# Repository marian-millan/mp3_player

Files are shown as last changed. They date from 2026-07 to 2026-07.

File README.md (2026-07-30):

<div align="center">

# Portable MP3 Player

### A custom, distraction-free music player inspired by retro physical media

**KiCad 9 · Arduino · DFPlayer Mini · SSD1306 OLED**

</div>

## Overview

We love music, but wanted a way to listen without constantly reaching for a
phone and getting distracted. Inspired by the tactile feel of retro physical
media, we set out to build a dedicated hardware MP3 player.

This repository contains versioned hardware designs, assembled-board models,
and Arduino firmware. The player combines physical transport controls and a
rotary volume encoder with a compact OLED interface.

## Features

- Standalone MP3 playback through a DFRobot DFPlayer Mini
- 128 × 64 SSD1306 OLED interface
- Previous, play/pause, and next track buttons
- Rotary encoder volume control
- Custom KiCad schematic and two-layer PCB layout
- STEP model of the assembled board

## Repository Layout

| Path | Contents |
| --- | --- |
| [`versions/v1/firmware`](versions/v1/firmware) | Version 1 Arduino firmware |
| [`versions/v1/hardware/mp3_player_schematic_v1.kicad_sch`](versions/v1/hardware/mp3_player_schematic_v1.kicad_sch) | Version 1 KiCad schematic |
| [`versions/v1/hardware/mp3_player_pcb_v1.kicad_pcb`](versions/v1/hardware/mp3_player_pcb_v1.kicad_pcb) | Version 1 KiCad PCB layout |
| [`versions/v1/hardware/mp3_player_assembly_v1.step`](versions/v1/hardware/mp3_player_assembly_v1.step) | Version 1 assembled-board model |
| [`versions/v2`](versions/v2) | Version 2 placeholder—in development |

```text
versions/
├── v1/
│   ├── firmware/
│   │   └── mp3_player_v1/
│   │       └── mp3_player_v1.ino
│   └── hardware/
│       ├── mp3_player_assembly_v1.step
│       ├── mp3_player_pcb_v1.kicad_pcb
│       └── mp3_player_schematic_v1.kicad_sch
└── v2/
    └── README.md
```

### Versioning Convention

Each release keeps its firmware and hardware together under
`versions/v<release>`. Project artifacts follow the
`descriptive_name_v<release>.<extension>` naming pattern.

New iterations should be added as sibling directories rather than overwriting
earlier versions. Arduino sketches are kept in matching directories because
the Arduino IDE expects a sketch and its containing directory to share a name.

## Firmware

### Requirements

- Arduino IDE or Arduino CLI
- An Arduino-compatible board configured for the project hardware
- [DFRobotDFPlayerMini](https://github.com/DFRobot/DFRobotDFPlayerMini)
- [U8g2](https://github.com/olikraus/u8g2)

`SoftwareSerial`, `SPI`, and `Wire` are supplied by the Arduino platform.

### Pin Map

| Function | Pin |
| --- | ---: |
| Previous track button | D2 |
| Play/pause button | D3 |
| Next track button | D4 |
| Rotary encoder A | D8 |
| Rotary encoder B | D9 |
| DFPlayer serial | D10 / D11 |
| OLED display | Hardware I²C |

The buttons use the microcontroller's internal pull-up resistors and are active
low. Playback actions occur when a button is released.

### Upload

1. Install the `DFRobotDFPlayerMini` and `U8g2` libraries with the Arduino
   Library Manager.
2. Open
   [`versions/v1/firmware/mp3_player_v1/mp3_player_v1.ino`](versions/v1/firmware/mp3_player_v1/mp3_player_v1.ino).
3. Select the correct board and serial port.
4. Compile and upload the sketch.
5. Insert a prepared microSD card into the DFPlayer Mini and power the player.

On startup, the firmware initializes the display, sets the volume to `20`, and
starts the first track. The current interface labels tracks as
`trackNNN.mp3` using the file number reported by the DFPlayer.

## Current Status

Version 1 includes the complete design sources and an initial working firmware
implementation. The firmware currently focuses on core playback, volume
control, and a minimal track-number interface; metadata browsing and richer
error reporting are not yet implemented.

Version 2 is currently in development. Its directory is reserved, but no
hardware or firmware artifacts have been published yet.

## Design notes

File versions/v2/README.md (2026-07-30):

# MP3 Player v2

> **Status:** In development

This directory is reserved for version 2 of the MP3 player. Hardware designs,
firmware, and supporting files will be added as they become available.

Version 2 artifacts should follow the repository's `_v2` filename convention
and use the following structure:

```text
v2/
├── firmware/
└── hardware/
```

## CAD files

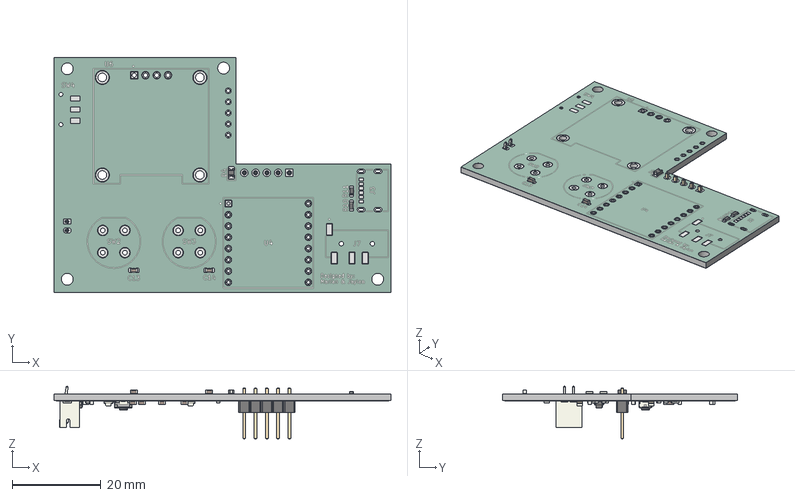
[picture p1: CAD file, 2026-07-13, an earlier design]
versions/v1/hardware/mp3_player_assembly_v1.step
76.0 x 53.0 x 11.9 mm
D_0805_2012Metric
C_0603_1608Metric x 13
R_0603_1608Metric x 16
PinHeader_1x05_P2.54mm_Vertical
Fuse_0805_2012Metric
LED_0805_2012Metric x 2
SOT-23-6
JST_PH_B2B-PH-K_1x02_P2.00mm_Vertical
SW_Push_SPST_NO_Alps_SKRK
mp3_player_copper
mp3_player_pad
mp3_player_via
mp3_player_silkscreen x 2
mp3_player_soldermask x 2
mp3_player_PCB

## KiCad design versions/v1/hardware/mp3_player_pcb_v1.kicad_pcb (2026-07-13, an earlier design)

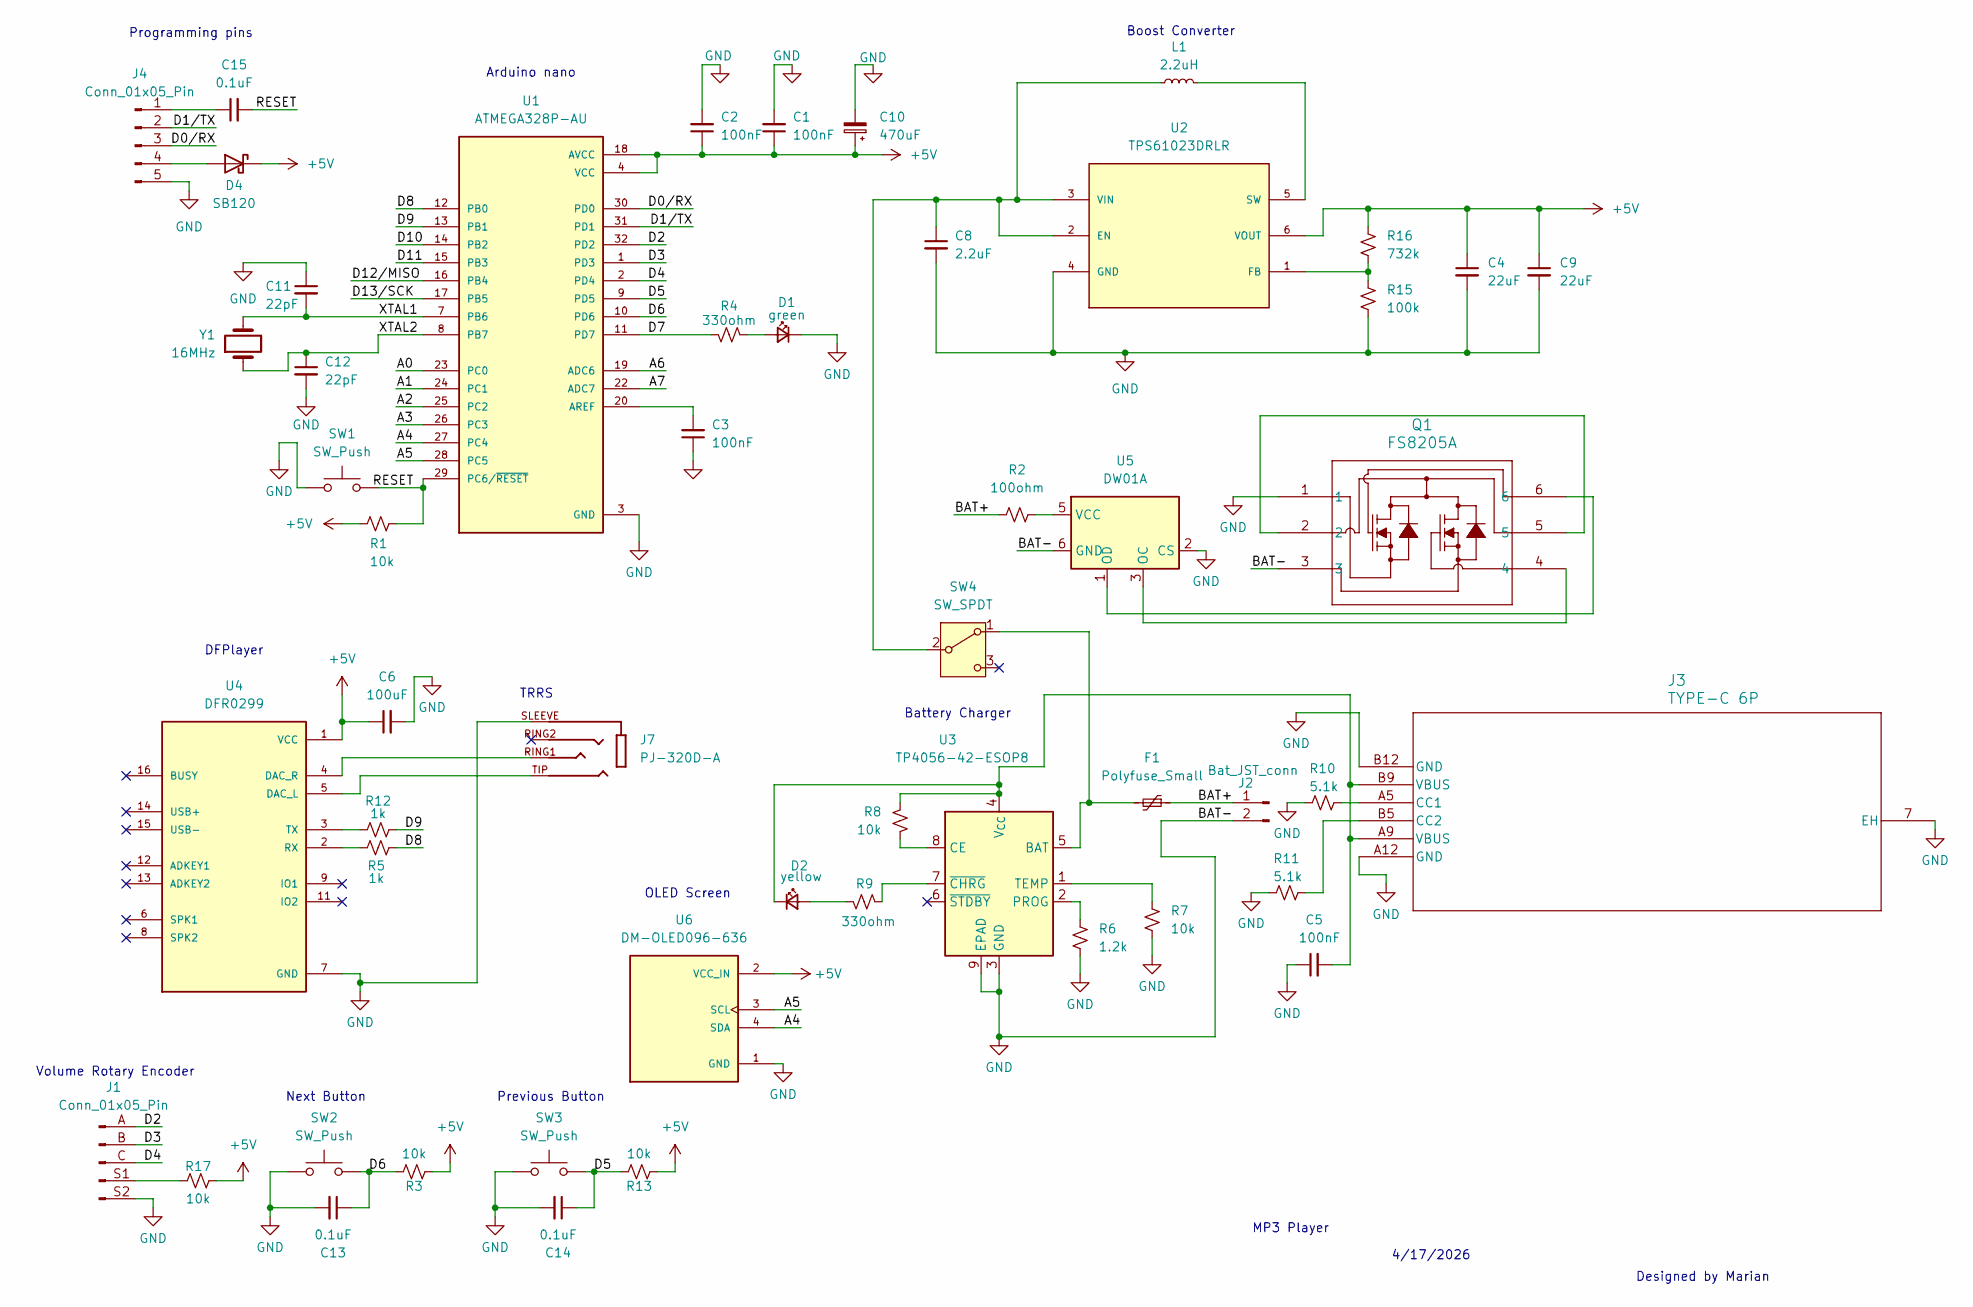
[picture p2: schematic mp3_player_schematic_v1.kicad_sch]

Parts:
C1, C2, C3, C5: 100nF; C_0603_1608Metric
C4, C9: 22uF; C_0603_1608Metric
C6: 100uF; C_0603_1608Metric
C8: 2.2uF; C_0603_1608Metric
C10: 470uF; CAP-SMD_BD6.3-L6.6-W6.6-FD
C11, C12: 22pF; C_0603_1608Metric
C13, C14, C15: 0.1uF; C_0603_1608Metric
D1: green; LED_0805_2012Metric
D2: yellow; LED_0805_2012Metric
D4: SB120; D_0805_2012Metric
F1: Polyfuse_Small; Fuse_0805_2012Metric
J1: Conn_01x05_Pin; rotary_encoder_socket_pads
J2: Bat_JST_conn; JST_PH_B2B-PH-K_1x02_P2.00mm_Vertical
J3: TYPE-C 6P; CONN_TYPE-C-6P_SHN
J4: Conn_01x05_Pin; PinHeader_1x05_P2.54mm_Vertical
J7: PJ-320D-A; HRO_PJ-320D-A; PARTREV B
L1: 2.2uH; IND-SMD_L4.9-W4.5
Q1: FS8205A; FS2805
R1, R3, R7, R8, R13, R17: 10k; R_0603_1608Metric
R2: 100ohm; R_0603_1608Metric
R4, R9: 330ohm; R_0603_1608Metric
R5, R12: 1k; R_0603_1608Metric
R6: 1.2k; R_0603_1608Metric
R10, R11: 5.1k; R_0603_1608Metric
R15: 100k; R_0603_1608Metric
R16: 732k; R_0603_1608Metric
SW1: SW_Push; SW_Push_SPST_NO_Alps_SKRK
SW2, SW3: SW_Push; pushbutton
SW4: SW_SPDT; SW-SMD_MST-12D18G4-SPDT-SLIDE-SWITCH
U1: ATMEGA328P-AU; ATPMEGA328P; PARTREV 8271A
U2: TPS61023DRLR; MANUFACTURER_PART_NUMBER TPS61023DRLR
U3: TP4056-42-ESOP8; SOIC-8-1EP_3.9x4.9mm_P1.27mm_EP2.41x3.3mm_ThermalVias
U4: DFR0299; MODULE_DFR0299
U5: DW01A; SOT-23-6
U6: DM-OLED096-636; OLED_screen; PARTREV 2018-09-10
Y1: 16MHz; XTAL_X49SM_S2_YXC

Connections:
+5V: C1.1, C2.1, C4.1, C6.1, C9.1, C10.1, D4.1 (K), R1.1, R3.2, R13.2, R16.1, R17.1, U1.4 (VCC), U1.6 (VCC), U1.18 (AVCC), U2.6 (VOUT), U4.1 (VCC), U6.2 (VCC_IN)
/A0: U1.23 (PC0)
/A1: U1.24 (PC1)
/A2: U1.25 (PC2)
/A3: U1.26 (PC3)
/A4: U1.27 (PC4), U6.4 (SDA)
/A5: U1.28 (PC5), U6.3 (SCL)
/A6: U1.19 (ADC6)
/A7: U1.22 (ADC7)
/BAT+: F1.1, J2.1, R2.1
/D0/RX: J4.3, U1.30 (PD0)
/D1/TX: J4.2, U1.31 (PD1)
/D2: J1.A (Pin_1), U1.32 (PD2)
/D3: J1.B (Pin_2), U1.1 (PD3)
/D4: J1.C (Pin_3), U1.2 (PD4)
/D5: C14.1, R13.1, SW3.2, U1.9 (PD5)
/D6: C13.1, R3.1, SW2.2, U1.10 (PD6)
/D7: R4.2, U1.11 (PD7)
/D8: R5.2, U1.12 (PB0)
/D9: R12.2, U1.13 (PB1)
/D10: U1.14 (PB2)
/D11: U1.15 (PB3)
/D12/MISO: U1.16 (PB4)
/D13/SCK: U1.17 (PB5)
/RESET: C15.2, R1.2, SW1.2, U1.29 (PC6/~RESET)
/XTAL1: C11.2, U1.7 (PB6), Y1.2
/XTAL2: C12.1, U1.8 (PB7), Y1.1
GND: C1.2, C2.2, C3.1, C4.2, C5.1, C6.2, C8.2, C9.2, C10.2, C11.1, C12.2, C13.2, C14.2, D1.1 (K), J1.S2 (Pin_5), J2.2, J3.7 (EH), J3.A12 (GND), J3.B12 (GND), J4.5, J7.SLEEVE, Q1.1, Q1.3, R6.2, R7.2, R10.2, R11.2, R15.2, SW1.1, SW2.1, SW3.1, U1.3 (GND), U1.5 (GND), U1.21 (GND), U2.4 (GND), U3.3 (GND), U3.9 (EPAD), U4.7 (GND), U4.10 (GND), U5.2 (CS), U5.6 (GND), U6.1 (GND)
unnamed: D1.2 (A), R4.1
unnamed: D2.2 (A), R9.2
unnamed: C5.2, D2.1 (K), J3.A9 (VBUS), J3.B9 (VBUS), R8.1, U3.4 (V_{CC})
unnamed: D4.2 (A), J4.4
unnamed: J1.S1 (Pin_4), R17.2
unnamed: J3.A5 (CC1), R10.1
unnamed: J3.B5 (CC2), R11.1
unnamed: C15.1, J4.1
unnamed: Q1.2, Q1.5
unnamed: F1.2, SW4.1 (A), U3.5 (BAT)
unnamed: C8.1, L1.1, SW4.2 (B), U2.2 (EN), U2.3 (VIN)
unnamed: C3.2, U1.20 (AREF)
unnamed: R15.1, R16.2, U2.1 (FB)
unnamed: L1.2, U2.5 (SW)
unnamed: R8.2, U3.8 (CE)
unnamed: R6.1, U3.2 (PROG)
unnamed: R7.1, U3.1 (TEMP)
unnamed: R9.1, U3.7 (~CHRG)
unnamed: J7.TIP, U4.5 (DAC_L)
unnamed: J7.RING1, U4.4 (DAC_R)
unnamed: R5.1, U4.2 (RX)
unnamed: R12.1, U4.3 (TX)
unnamed: Q1.4, U5.3 (OC)
unnamed: Q1.6, U5.1 (OD)
unnamed: R2.2, U5.5 (VCC)

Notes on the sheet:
4/17/2026
Previous Button
Programming pins
MP3 Player
Boost Converter
OLED Screen
Next Button
Arduino nano
Designed by Marian
Battery Charger
Volume Rotary Encoder
DFPlayer
TRRS

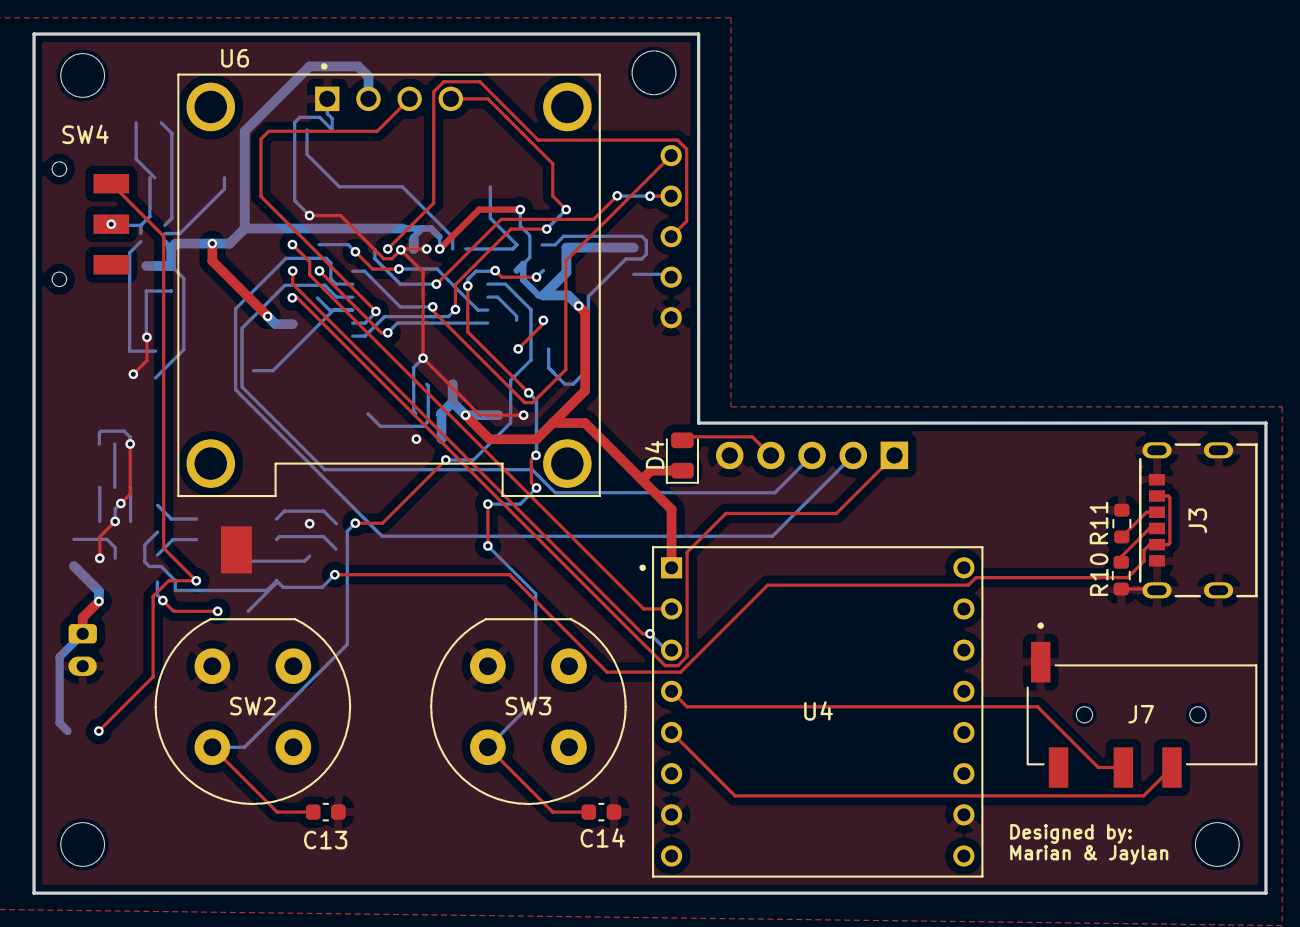
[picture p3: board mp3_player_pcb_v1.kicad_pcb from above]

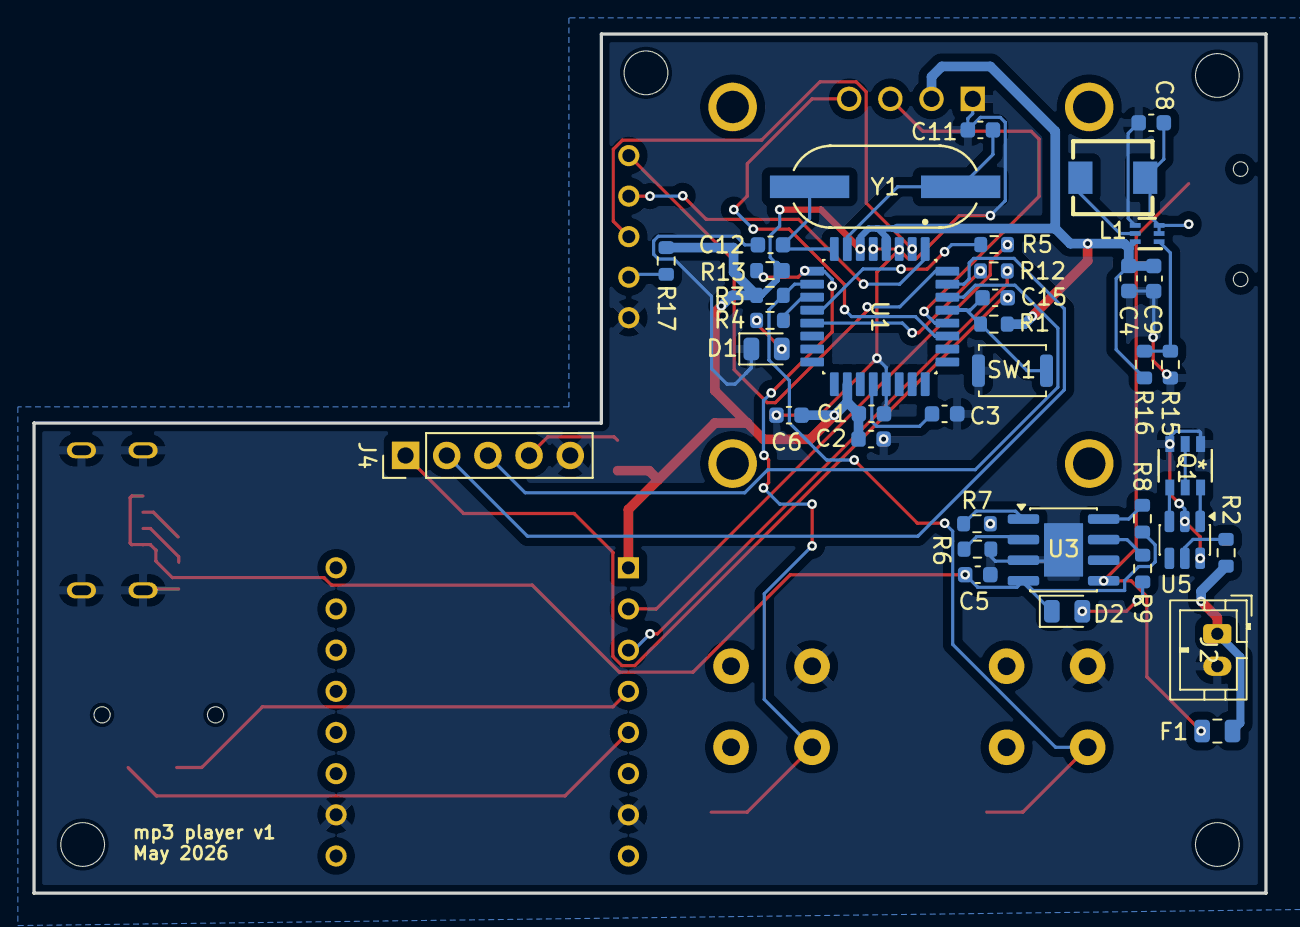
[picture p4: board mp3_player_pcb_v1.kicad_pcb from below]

Board: 2 copper layers, 76.0 x 53.0 mm, 51 parts (38 on the bottom side), 43 nets.

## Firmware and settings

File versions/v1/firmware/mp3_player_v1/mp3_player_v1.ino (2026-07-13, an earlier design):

#include <SoftwareSerial.h>
#include <DFRobotDFPlayerMini.h>
#include <SPI.h>
#include <Wire.h>
#include <U8g2lib.h>

// ========== OLED (U8g2) ==========
U8G2_SSD1306_128X64_NONAME_1_HW_I2C display(U8G2_R0, U8X8_PIN_NONE);

// ========== MP3 Player ==========
#define MP3_TX 10
#define MP3_RX 11
SoftwareSerial softwareSerial(MP3_TX, MP3_RX);
DFRobotDFPlayerMini player;

// ========== Buttons ==========
#define BUTTON_BACK 2
#define BUTTON_PLAY 3
#define BUTTON_NEXT 4
bool prevBack = HIGH;
bool prevPlay = HIGH;
bool prevNext = HIGH;

// ========== Encoder ==========
#define ENCODER_PIN_A 8
#define ENCODER_PIN_B 9
int prevEncoderPinA;
int currEncoderPinA;

bool isPlaying = true;
bool redraw = true;

// ================= SETUP =================
void setup() {
  Wire.begin();
  Serial.begin(115200);

  buttons_init();
  encoder_init();
  oled_display_init();
  df_player_init();
}

// ================= LOOP =================
void loop() {
  handle_volume();
  handle_buttons();

  bool backHeld = digitalRead(BUTTON_BACK) == LOW;
  bool playHeld = digitalRead(BUTTON_PLAY) == LOW;
  bool nextHeld = digitalRead(BUTTON_NEXT) == LOW;

  // redraw only if something changed
  if (redraw) {
    mp3_player_ui(backHeld, playHeld, nextHeld);
    redraw = false;
  }
}

// ================= INIT =================
void buttons_init() {
  pinMode(BUTTON_BACK, INPUT_PULLUP);
  pinMode(BUTTON_PLAY, INPUT_PULLUP);
  pinMode(BUTTON_NEXT, INPUT_PULLUP);
}

void encoder_init() {
  pinMode(ENCODER_PIN_A, INPUT);
  pinMode(ENCODER_PIN_B, INPUT);
  prevEncoderPinA = digitalRead(ENCODER_PIN_A);
}

void df_player_init() {
  softwareSerial.begin(9600);

  if (player.begin(softwareSerial)) {
    delay(500);
    player.volume(20);
    player.play(1);
  }
}

void oled_display_init() {
  display.begin();

  const char* title = "Starting Up...";

  display.firstPage();
  do {
    display.drawFrame(0, 0, 128, 64);

    display.setFont(u8g2_font_6x10_mf);
    int w = display.getStrWidth(title);
    display.drawStr((128 - w) / 2, 34, title);

    // // Loading bar
    // int barX = 14;
    // int barY = 40;
    // int barWidth = 100;
    // int barHeight = 10;

    // display.drawFrame(barX, barY, barWidth, barHeight);

    // for (int i = 0; i <= barWidth - 2; i++) {
    //   display.drawBox(barX + 1, barY + 1, i, barHeight - 2);
    //   display.sendBuffer();  // force update for animation
    //   delay(1);
    // }
  } while (display.nextPage());
}

// ================= UI =================
void mp3_player_ui(bool backHeld, bool playHeld, bool nextHeld) {
  display.firstPage();
  do {
    display.drawFrame(0, 0, 128, 64);

    // ===== TRACK NAME =====
    char track[20];
    snprintf(track, sizeof(track), "track%03d.mp3", player.readCurrentFileNumber());
    display.setFont(u8g2_font_6x10_mf);
    int w = display.getStrWidth(track);
    display.drawStr((128 - w) / 2, 24, track);

    // ===== BUTTON ROW =====
    int centerY = 44;
    int centerX = 64;
    int spacing = 36;

    draw_back_ui(centerX - spacing, centerY, backHeld);
    draw_play_ui(centerX, centerY, playHeld);
    draw_next_ui(centerX + spacing, centerY, nextHeld);

  } while (display.nextPage());
}

// ================= ICONS =================
void draw_back_ui(int x, int y, bool held) {
  int size = 8;

  if (held) {
    display.drawTriangle(x, y, x + size * 1.5, y - size, x + size * 1.5, y + size);
    display.drawTriangle(x - size * 1.5, y, x, y - size, x, y + size);
  } else {
    display.drawTriangle(x, y, x + size * 1.5, y - size, x + size * 1.5, y + size);
    display.drawTriangle(x - size * 1.5, y, x, y - size, x, y + size);
  }
}

void draw_play_ui(int x, int y, bool held) {
  int size = 8;

  if (isPlaying) {
    if (held) {
      display.drawFrame(x - 5, y - size, 3, size * 2);
      display.drawFrame(x + 2, y - size, 3, size * 2);
    } else {
      display.drawBox(x - 5, y - size, 3, size * 2);
      display.drawBox(x + 2, y - size, 3, size * 2);
    }
  } else {
    if (held) {
      display.drawTriangle(x - size, y - size, x - size, y + size, x + size + 1, y);
    } else {
      display.drawTriangle(x - size, y - size, x - size, y + size, x + size + 1, y);
    }
  }
}

void draw_next_ui(int x, int y, bool held) {
  int size = 8;

  if (held) {
    display.drawTriangle(x, y, x - size * 1.5, y - size, x - size * 1.5, y + size);
    display.drawTriangle(x + size * 1.5, y, x, y - size, x, y + size);
  } else {
    display.drawTriangle(x, y, x - size * 1.5, y - size, x - size * 1.5, y + size);
    display.drawTriangle(x + size * 1.5, y, x, y - size, x, y + size);
  }
}

// ================= INPUT =================
void handle_buttons() {
  bool backState = digitalRead(BUTTON_BACK);
  bool playState = digitalRead(BUTTON_PLAY);
  bool nextState = digitalRead(BUTTON_NEXT);

  // detect ANY change (press or release)
  if (backState != prevBack || playState != prevPlay || nextState != prevNext) {
    redraw = true;
  }

  if (prevBack == LOW && backState == HIGH) {
    player.previous();
    redraw = true;
  }

  if (prevPlay == LOW && playState == HIGH) {
    isPlaying = !isPlaying;
    if (isPlaying) player.start();
    else player.pause();
    redraw = true;
  }

  if (prevNext == LOW && nextState == HIGH) {
    player.next();
    redraw = true;
  }

  prevBack = backState;
  prevPlay = playState;
  prevNext = nextState;
}

void handle_volume() {
  currEncoderPinA = digitalRead(ENCODER_PIN_A);
  if (currEncoderPinA != prevEncoderPinA) {
    if (digitalRead(ENCODER_PIN_B) != currEncoderPinA) {
      player.volumeUp();
    } else {
      player.volumeDown();
    }
  }
  prevEncoderPinA = currEncoderPinA;
}

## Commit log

2026-07-13 Create board_version1.step
    Test
    [version1.step]
2026-07-13 full_assembled_board.step
    This file contains the full PCB 3D model
    [full_assembled_board.step, version1.step]
2026-07-30 Refractor repo
    [mp3_player_assembly_v1.step, mp3_player_pcb_v1.kicad_pcb, mp3_player_schematic_v1.kicad_sch]

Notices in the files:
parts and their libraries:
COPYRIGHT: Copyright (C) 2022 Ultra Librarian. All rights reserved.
